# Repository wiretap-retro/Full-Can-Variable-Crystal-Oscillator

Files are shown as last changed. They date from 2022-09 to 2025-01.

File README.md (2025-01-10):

# Full Can Variable Crystal Oscillator
A full can size crystal oscillator that can be programmed for the frequency you need.

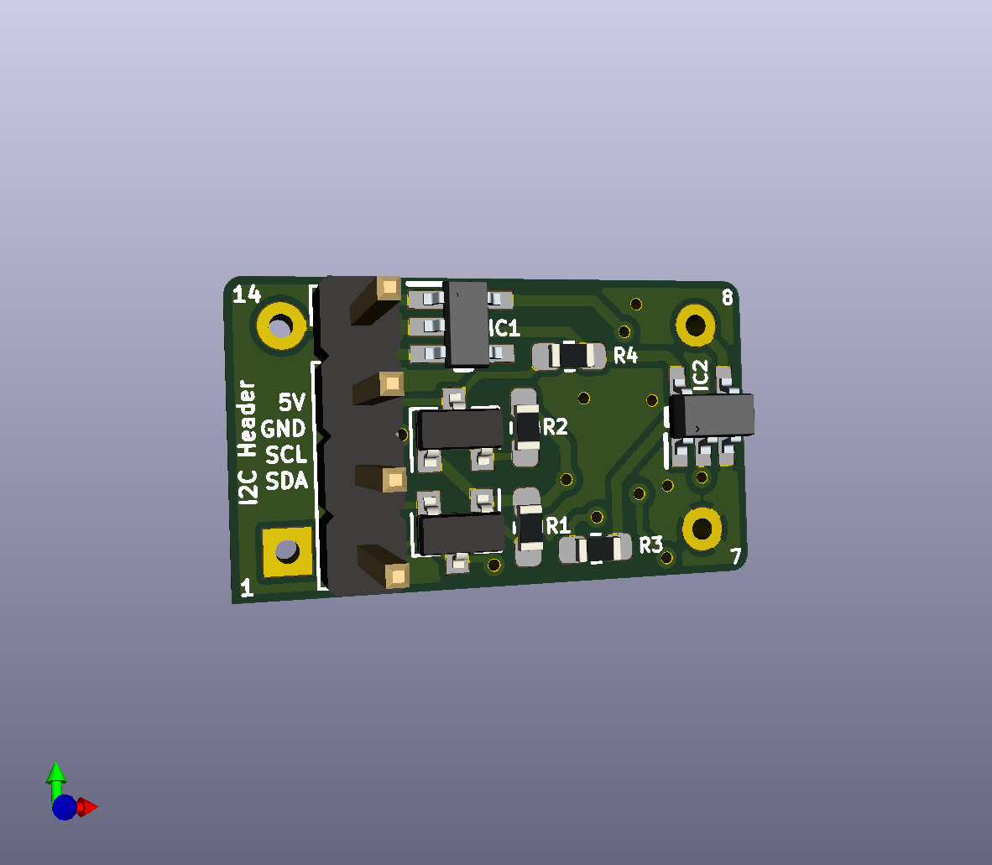
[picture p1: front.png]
front

\
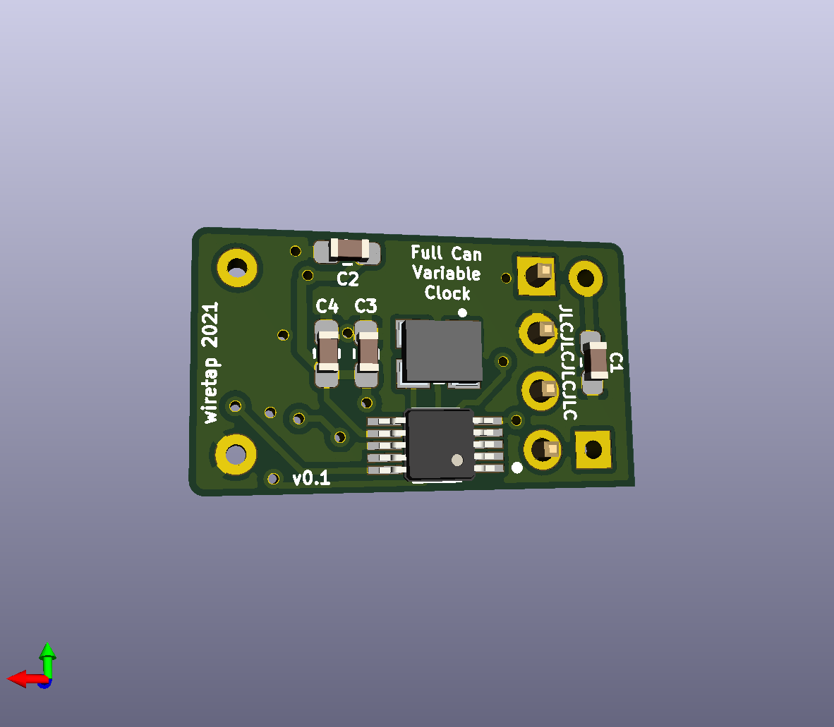
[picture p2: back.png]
back


## Info
This variable crystal oscillator in a full-can form factor can be programmed from frequencies 8kHz to 160MHz. An arduino or pi can easily be used to hook up to the i2c port to set the frequency. Use a 3.3V SMD crystal oscillator and install into a 5V system.
\
\
This project is based on the Adafruit Si5351 found here: https://learn.adafruit.com/adafruit-si5351-clock-generator-breakout
\
Vogons thread for more info: https://www.vogons.org/viewtopic.php?t=82731

## Programming
The Adafruit tutorial found here is how this device is programmed: https://learn.adafruit.com/adafruit-si5351-clock-generator-breakout/wiring-and-test \
In-circuit programmer hat: https://github.com/wiretap-retro/Full-Can-Variable-Programmer/

## Notes
This project does not utilize the clock enable pin (EN on most datasheets), so it can only be used in parent boards that don't make active use of the clock enable/disable function.

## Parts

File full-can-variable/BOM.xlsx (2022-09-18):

Reference | Value | Footprint | Description | Manufacturer | Mouser Part Number
C1, C2 | 1uF | Capacitor_SMD:C_0603_1608Metric_Pad1.05x0.95mm_HandSolder | 0603 1uF Capacitor SMD | Taiyo Yuden | 963-LMK107B7105KAHT
C3, C4 | 0.47uF | Capacitor_SMD:C_0603_1608Metric_Pad1.05x0.95mm_HandSolder | 0603 0.47uF Capacitor SMD | Samsung | 187-CL10B474KO8VPNC
IC1 | NCP164CSN330T1G | SOT95P275X110-5N | LDO Regulator Pos 3.3V 0.3A 5-Pin TSOP T/R | ON Semiconductor | 863-NCP164CSN330T1G
IC2 | SN74LV1T34DBVRG4 | SOT95P280X145-5N | Single Power Supply BUFFER Logic Level Shifter (no enable) | Texas Instruments | 595-SN74LV1T34DBVRG4
J1 | I2C | Connector_PinHeader_2.54mm:PinHeader_1x04_P2.54mm_Vertical | 1x04 2.54mm Pin Header | TE Connectivity | 571-5-103327-1
Q1, Q2 | BSS138-G | Package_TO_SOT_SMD:SOT-23 | BSS138 MOSFET | Onsemi | 863-BSS138-G
R1 - R4 | 10k | Resistor_SMD:R_0603_1608Metric_Pad1.05x0.95mm_HandSolder | 0603 10k ohm Resistor SMD | Vishay | 71-CRCW060310K0JNEAC
U1 | SI5351A-B02075-GT | SamacSys_Parts:Silicon_Laboratories-SI5351A-B02075-GT-0 | Programmable Clock Generator (MSOP-10 package) | Skyworks Solutions | 634-SI5351A-B02075GT
Y1 | ABM8G-25.000MHZ-4Y-T3 | ABM8G48000MHZ18D2YT | Abracon 25MHz Crystal Unit +/-30ppm SMD 4-Pin 3.2 x 2.5 x 1mm | ABRACON | 815-ABM8G-25-4YT3

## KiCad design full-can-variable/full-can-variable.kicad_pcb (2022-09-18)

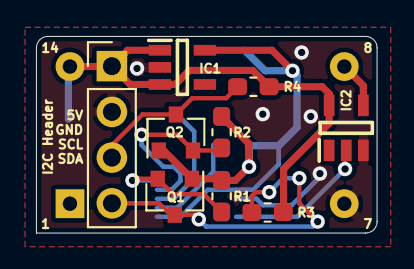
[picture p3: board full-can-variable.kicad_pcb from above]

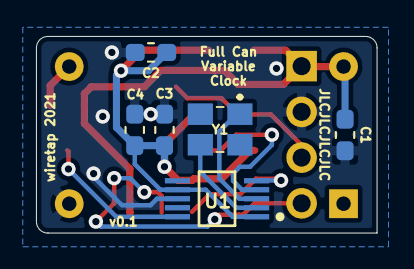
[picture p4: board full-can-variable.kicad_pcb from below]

Board: 2 copper layers, 18.9 x 10.9 mm, 16 parts (6 on the bottom side), 11 nets.

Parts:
C1: 1uF; C_0603_1608Metric_Pad1.05x0.95mm_HandSolder
C2: 0.1uF; C_0603_1608Metric_Pad1.05x0.95mm_HandSolder
C3, C4: 0.47uF; C_0603_1608Metric_Pad1.05x0.95mm_HandSolder
I2C Header: I2C; PinHeader_1x04_P2.54mm_Vertical
IC1: IC1; SOT95P275X110-5N
IC2: IC2; SOT95P280X145-5N
Q1, Q2: BSS138-G; SOT-23
R1, R2, R3, R4: 10k; R_0603_1608Metric_Pad1.05x0.95mm_HandSolder
U1: U1; Silicon_Laboratories-SI5351A-B02075-GT-0
X1: CXO_DIP14; Oscillator_DIP-14
Y1: Y1; ABM8G48000MHZ18D2YT

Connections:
/3VCLK: IC2.2, U1.10
/5VCLK: IC2.4, X1.8
/SCL_3V: Q2.2, R2.2, U1.4
/SCL_5V: I2C Header.3, Q2.3, R4.2
/SDA_3V: Q1.2, R1.2, U1.5
/SDA_5V: I2C Header.4, Q1.3, R3.2
/VDD: C2.1, C3.2, C4.2, IC1.5, Q1.1, Q2.1, R1.1, R2.1, U1.1, U1.7
/VIN: C1.1, I2C Header.1, IC1.1, IC1.3, IC2.5, R3.1, R4.1, X1.14
GND: C1.2, C2.2, C3.1, C4.1, I2C Header.2, IC1.2, IC2.3, U1.8, X1.7
unnamed: U1.2, Y1.3
unnamed: U1.3, Y1.1
